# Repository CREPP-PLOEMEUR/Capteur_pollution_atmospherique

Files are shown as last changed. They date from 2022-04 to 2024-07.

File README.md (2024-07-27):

<!--# Capteur de pollution atmosphérique -->
<!--$ Arduino-->
<!--$ Freecad-->
<!--+ 2019-2020-->
<!--% Un projet pour un capteur de pollution atmosphérique. Il indique si un certain nombre de particules fines dépasse la norme. -->

# Capteur de pollution atmosphérique

Un projet pour un capteur de pollution atmosphérique. Il indique si un certain nombre de particules fines dépasse la norme.

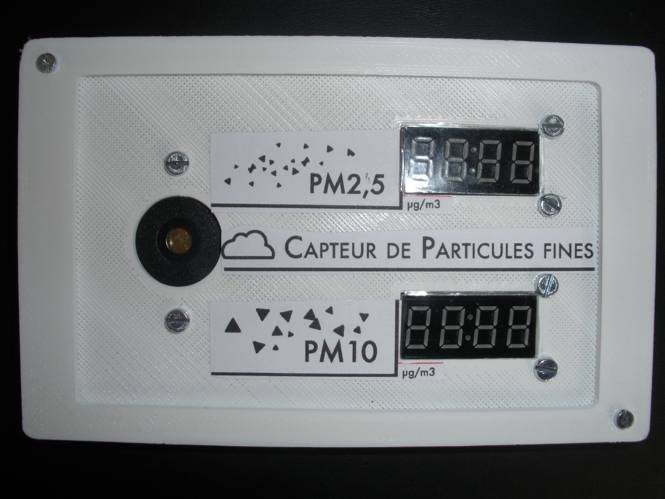
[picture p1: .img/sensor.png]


Maintenant votre boîtier en deux parties prêt, vous allez pouvoir passer au fixation des composants et au câblage de l'ensemble. On fera cela en 3 temps : 

- Fixer l’Arduino et le capteur de particules (SDS011) au fond du boîtier. Pour que ceux-ci ne bougent plus, munissez-vous de 7 paires boulons-écrous (diam. 2,5mm) et visez-les dans les 7 trous correspondants. 

- Ensuite prenez câbles et jumpers pour réaliser les câblage comme suit : 

- Arduino - pin 6 > RX (SDS011) 
- Arduino - pin 7 > TX (SDS011) 
- Arduino - pin 8 > CLK (TM1637 n°1) 
- Arduino - pin 9 > DIO (TM1637 n°1) 
- Arduino - pin 10 > CLK (TM1637 n°2) 
- Arduino - pin 11 > DIO (TM1637 n°2) 
- Arduino - pin 13 >Piezo 
- Arduino - 5v > 5v/Vcc (SDS011, TM1637 n°1 et TM1637 n°2) 
- Arduino - GND > GND (SDS011, Piezo, TM1637 n°1 et TM1637 n°2) 
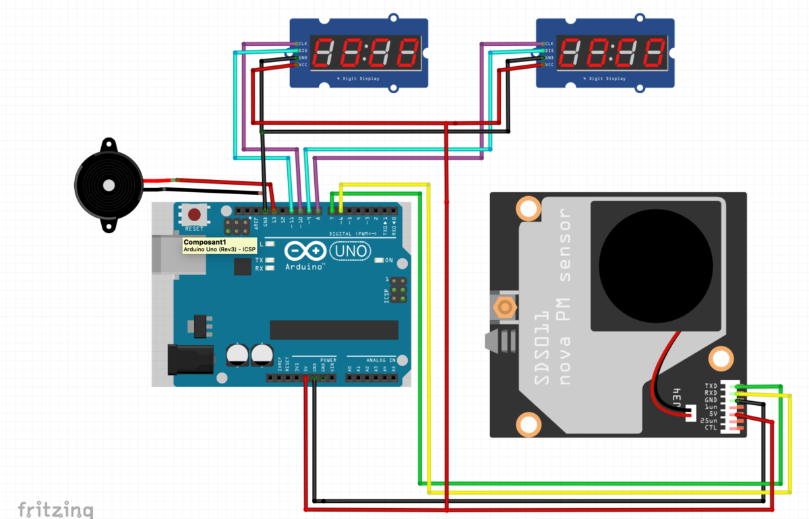
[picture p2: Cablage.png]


- Attention, la carte Arduino n'aura pas assez de pin 5v ni GND pour alimenter vos composants, nous vous conseillons donc de fabriquer des jumpers "1 entrée > 4 sorties" afin d'alimenter proprement votre circuit sans recourir à une breadboard.

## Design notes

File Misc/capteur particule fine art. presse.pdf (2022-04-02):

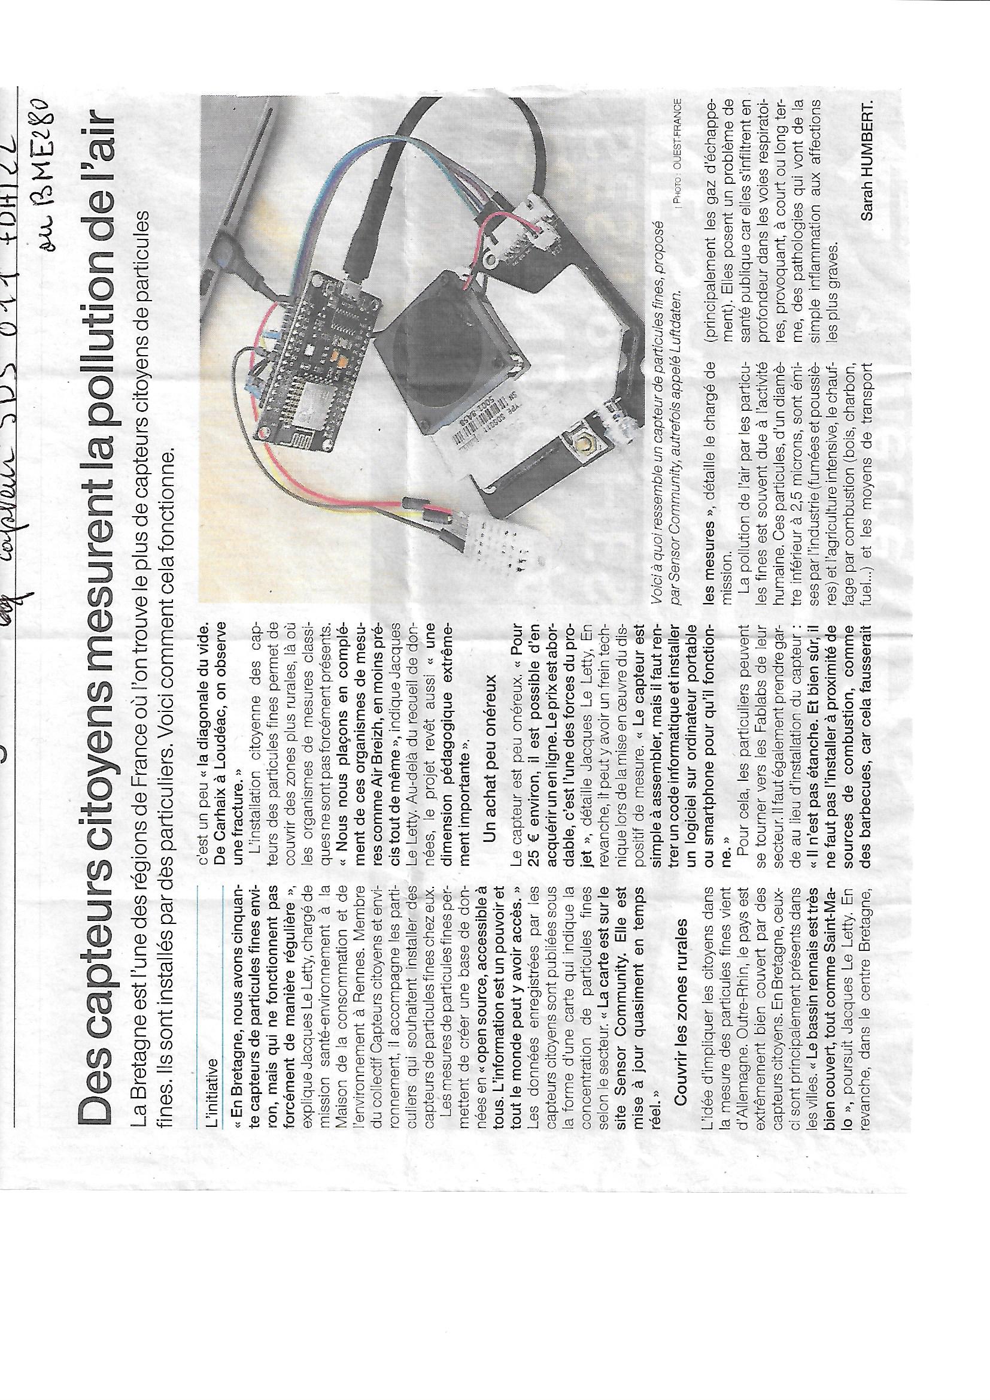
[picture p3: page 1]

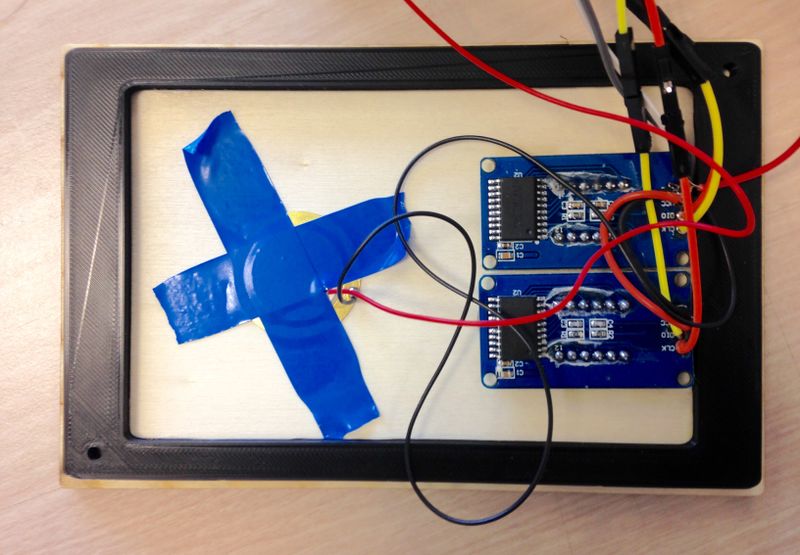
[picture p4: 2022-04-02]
Images/800px-Surveillez_vos_particules_fines_FullSizeRender62.jpg

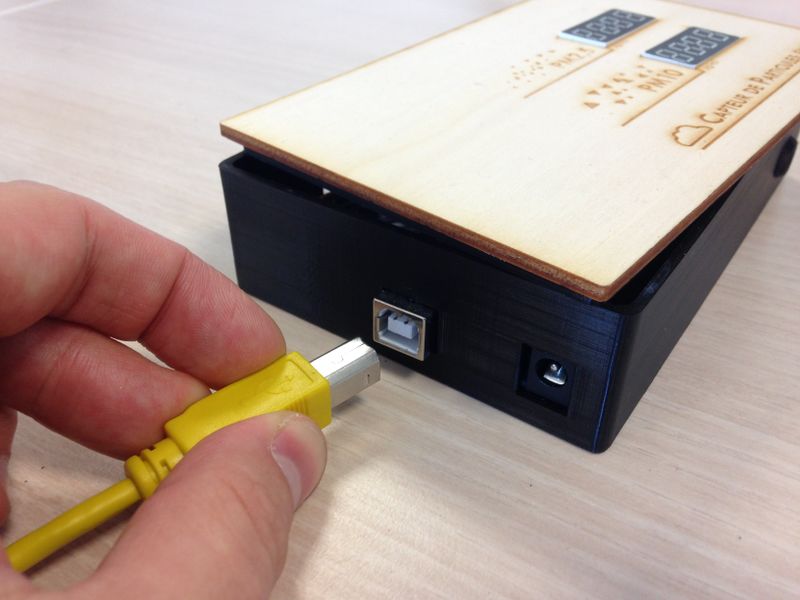
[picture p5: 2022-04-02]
Images/800px-Surveillez_vos_particules_fines_IMG_2858.JPG

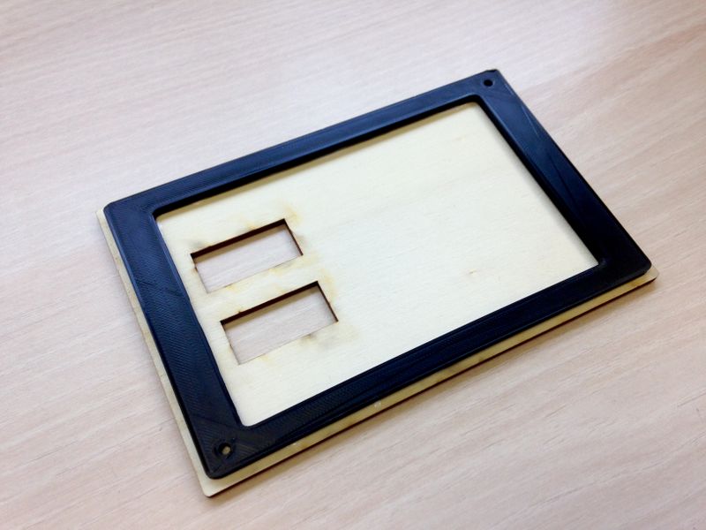
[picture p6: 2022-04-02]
Images/800px-Surveillez_vos_particules_fines_FullSizeRender2.jpg

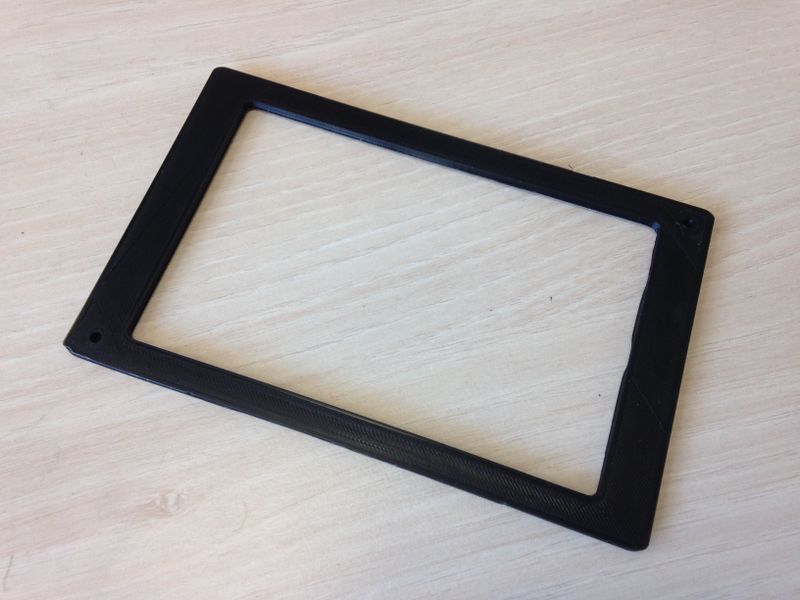
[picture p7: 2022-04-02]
Images/800px-Surveillez_vos_particules_fines_IMG_2856.JPG

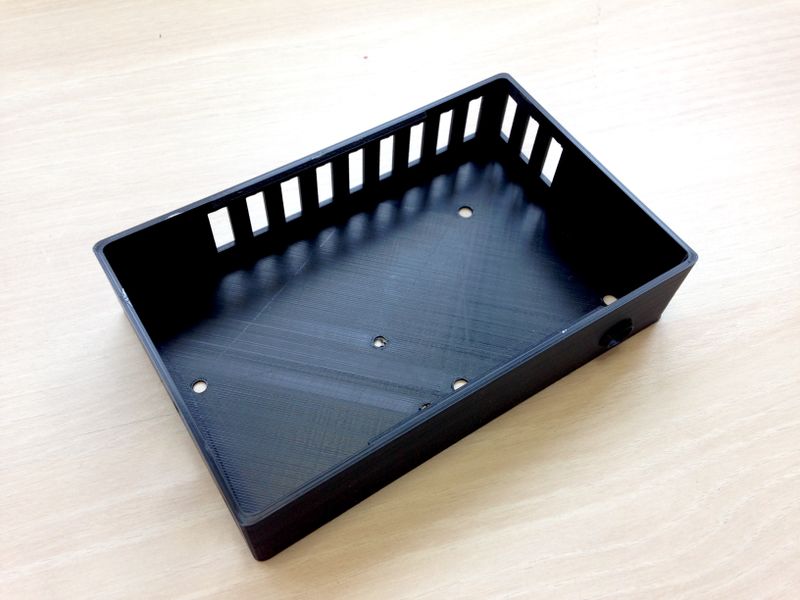
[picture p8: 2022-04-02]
Images/800px-Surveillez_vos_particules_fines_FullSizeRender3.jpg

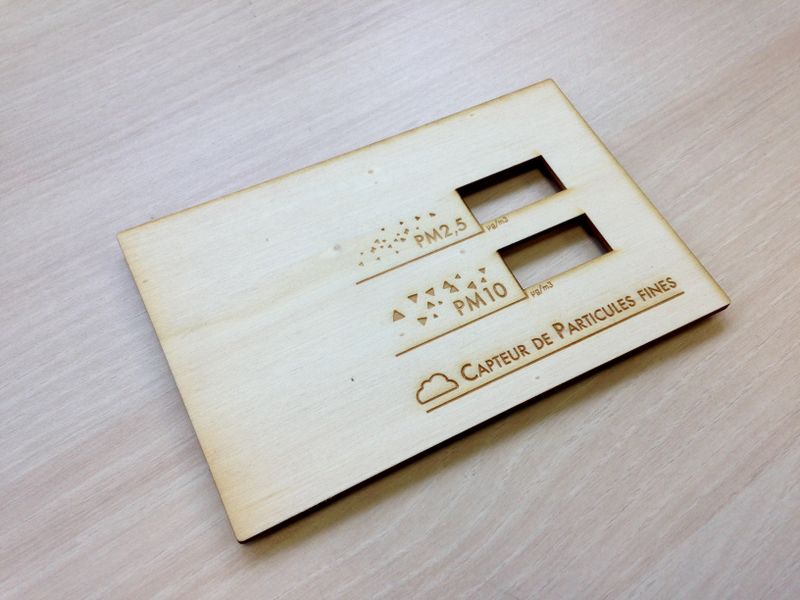
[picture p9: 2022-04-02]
Images/800px-Surveillez_vos_particules_fines_FullSizeRender4.jpg

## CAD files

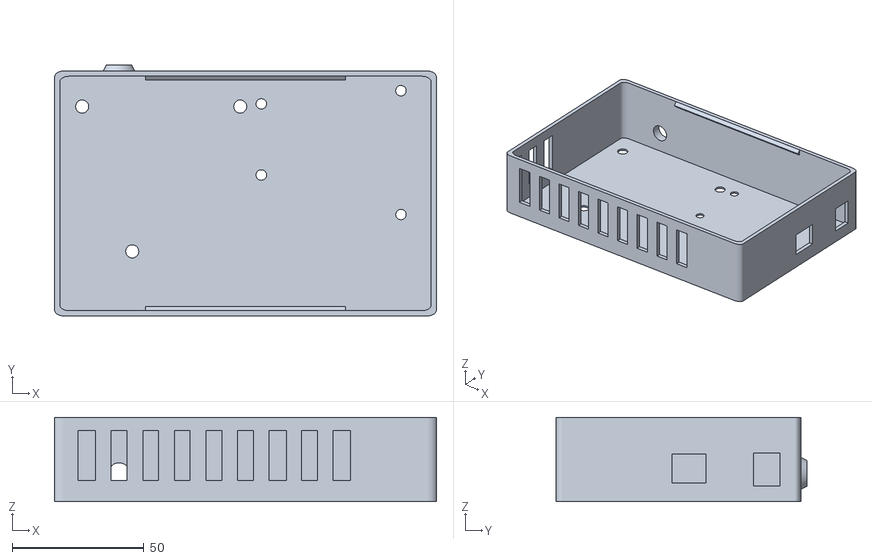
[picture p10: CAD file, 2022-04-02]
Misc/Surveillez_vos_particules_fines_Capteur_particules_PM_1_.stl
145.0 x 95.2 x 32.0

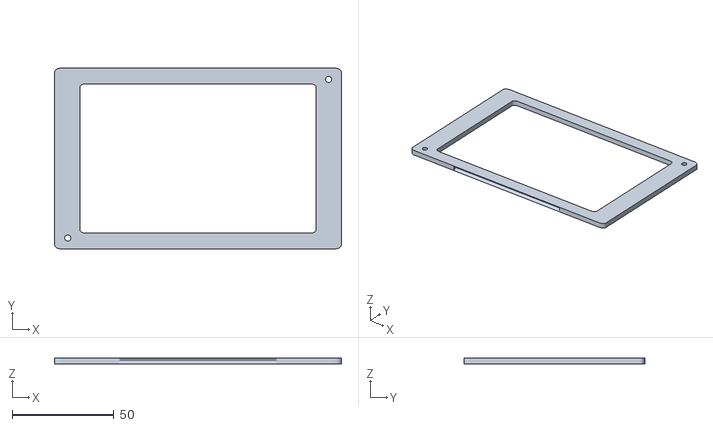
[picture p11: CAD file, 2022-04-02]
Misc/Surveillez_vos_particules_fines_Couvercle_PM.stl
140.8 x 88.8 x 3.00

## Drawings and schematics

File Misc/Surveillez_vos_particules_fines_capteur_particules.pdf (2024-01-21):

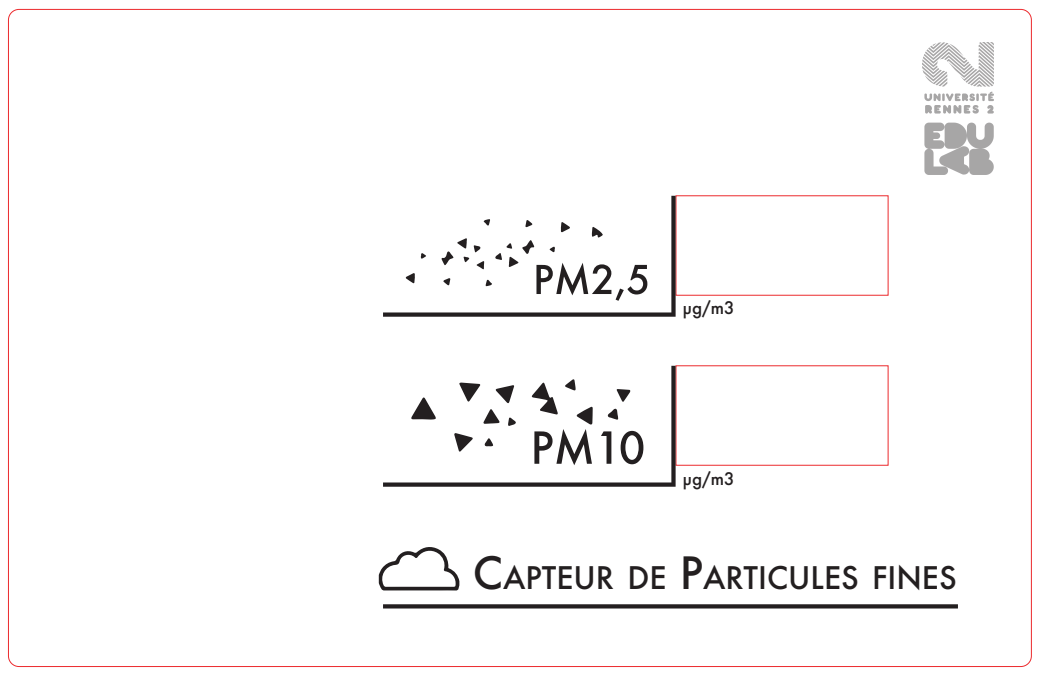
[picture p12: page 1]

CAPTEUR DE PARTICULES FINES

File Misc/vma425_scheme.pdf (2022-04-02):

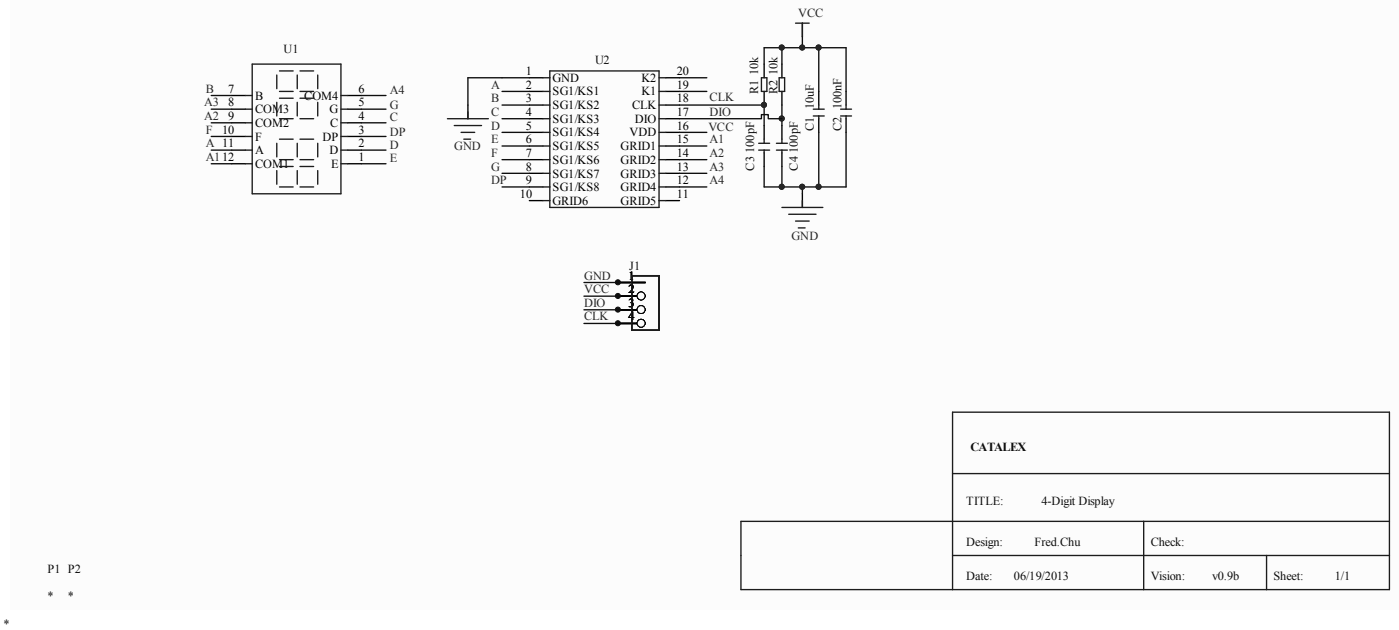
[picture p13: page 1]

Design: Fred.Chu | Check:

Date: 06/19/2013 | Vision: v0.9b | Sheet: 1/1

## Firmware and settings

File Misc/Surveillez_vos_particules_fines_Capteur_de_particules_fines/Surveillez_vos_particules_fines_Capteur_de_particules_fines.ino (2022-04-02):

//---CAPTEUR DE PARTICULES FINES----oct 2019 - Tony Vanpoucke (Edulab, Rennes 2)--------------------//
//                                                                                                  //
//   Petit capteur de particules fines avec affichage 7 segements et seuil d'alerte                 //
//--------------------------------------------------------------------------------------------------//

// ----- PARAMETRES MODIFIABLES ----------------------------------//

int SeuilPM25 = 15;       //Seuil d'alerte aux PM 2,5 (15 μg/m3 en moyenne annuelle)
int SeuilPM10 = 30;       //Seuil d'alerte aux PM 10 (30 μg/m3 en moyenne annuelle)
int Note = 1000;          //fréquence de la note d'alerte (1000 par défaut)
int nbBips = 4;           //nombre de bips par alertes (4 par défaut)
int clignotte = 400;      //vitesse de clignottement des messages d'alerte (400 par défaut)
float luminosite = 2.5;   //luminosité des écrans

// ----- Variables du programme

int PM10 = 0;
int PM25 = 0;
bool buzz = 0;

// ----- Bibliothèques utilisées

#include "SdsDustSensor.h"
#include <Arduino.h>
#include <TM1637Display.h>

// ----- Branchements arduino

int rxPin = 7;
int txPin = 6;
int piezoPin = 13;

// Branchelent cran 1
#define CLK1 10
#define DIO1 11

// Ecran 2
#define CLK2 8
#define DIO2 9

TM1637Display display1(CLK1, DIO1);
TM1637Display display2(CLK2, DIO2);

SdsDustSensor sds(rxPin, txPin);

// ----- INITIALISATION ---------------------------------------//

void setup()
{
  Serial.begin(9600);
  sds.begin();
  display1.setBrightness(luminosite);
  display2.setBrightness(luminosite);
  SeuilPM25 = SeuilPM25 * 100;
  SeuilPM10 = SeuilPM10 * 100;
}

// ----- PROGRAMME ---------------------------------------//

void loop()
{
  uint8_t blank[] = { 0x00, 0x00, 0x00, 0x00 };      //affichage vide
  PmResult pm = sds.readPm();                        //scan le capteur de particules
  if (pm.isOk()) {                                   //s'il fonctionne
    PM10 = ((pm.pm10) * 100);                        //stock les valeurs du capteur dans deux variables
    PM25 = ((pm.pm25) * 100);
    Serial.println(PM10);
    Serial.println(PM25);

    if ((SeuilPM25 < PM25) || (SeuilPM10 < PM10)) { //Si une des valeurs dépasse un seuil ...
      display1.showNumberDecEx(PM25, 64, false);    //Affiche les valeurs dans les écrans 7 segements
      display2.showNumberDecEx(PM10, 64, false);
      delay(clignotte);
      if (buzz == 0) {                              //Déclanche un signal sonore
          buzz = 1;
          Serial.println("buzz");
        for (int i = 0; i <= nbBips; i++) {
          tone(piezoPin, Note);
        delay(clignotte);
        noTone(piezoPin);
        delay(clignotte);
        }
        
      }
      if (SeuilPM25 < PM25) {                       //Fait clignotter l'affichage de PM25
        display1.setSegments(blank);
      }
      if (SeuilPM10 < PM10) {                       //Fait clignotter l'affichage de PM10
        display2.setSegments(blank);
      }
      delay(clignotte);

    }
    else {
      display1.showNumberDecEx(PM25, 64, false);    //Sinon valeurs dans les écrans 7 segements
      display2.showNumberDecEx(PM10, 64, false);
      buzz = 0;
    }
  }
}

// --------------------------------------------------------//
